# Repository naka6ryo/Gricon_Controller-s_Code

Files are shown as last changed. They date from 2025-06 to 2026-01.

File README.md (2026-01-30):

# Gricon_Controller-s_Code

2024/12/27に桃山大学テック部主催で開催されたハッカソンに出展した作品 **Gricon** のコントローラー側プログラムです（2024/12/28 時点）。

このArduinoプログラムは、IMU（姿勢センサ）、曲げセンサ、モーターを統合し、姿勢推定・屈曲検出・振動出力を通じて新しい入力体験を提供します。

公式サイト：https://gricon.netlify.app/

## 🎥 デモ動画

Gricon デモ動画 (https://youtu.be/qLPBSaw1i-E?si=rnXXbKDZcDVdmmQi)

---

## 🔗 関連リンク

- 🎮 **ゲーム側のプログラム（Unity）**  
  https://github.com/kdix-23-240/NewControllerProject-MomoyamaHack

- 📄 **作品に関する情報・ソースコードの解説・開発の流れの説明（Notion）**  
  https://flossy-band-678.notion.site/Gricon-Arduino-Unity-16a9ff2ca96c8032b9a5cc3768512383?pvs=4

---

## 📌 特徴 / Features

- **9軸IMUセンサ（LSM9DS1）** によるピッチ・ロール・ヨーの推定  
- **Madgwickフィルタ** による高精度な姿勢推定  
- **曲げセンサ** を使ったアナログ入力処理と平滑化  
- **加速度のグローバル変換・振動検出** によるリアクティブ入力対応  
- **振動モーター出力** を通じたハプティクスフィードバック  
- **シリアル通信** による外部機器（ゲーム）との双方向連携  

---

## 🔧 使用ハードウェア

- Arduino Nano 33 BLE Sense または LSM9DS1 搭載の互換ボード  
- 曲げセンサ（アナログ入力：A7）  
- 振動モーター（デジタル出力：D9）  
- 外部通信：Serial1（9600bps）

---

## 📷 回路図

以下は、本デバイスの回路図です（Arduino Nano 33 BLE + 曲げセンサ + モータ + Bluetooth構成）：

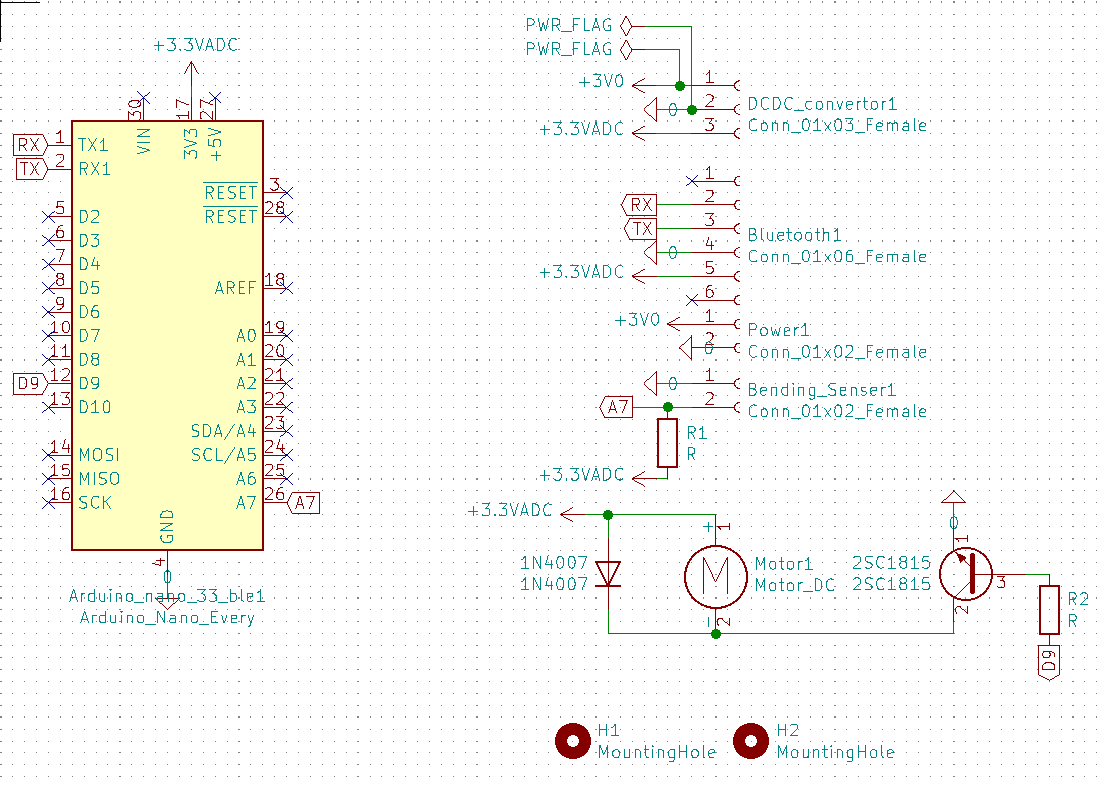
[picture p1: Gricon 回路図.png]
Gricon回路図


---

## 📤 センサ出力フォーマット

コントローラは以下のフォーマットで**バイナリ形式**のデータを送信します。

[S][pitch (2 bytes)][roll (2 bytes)][yaw (2 bytes)][bend (1 byte)]

- `S`: データ開始を示すヘッダ（1バイト）  
- `pitch`, `roll`, `yaw`: 姿勢角（各2バイト、0.1°単位）  
- `bend`: 曲げセンサ値（0〜20の範囲にクランプ）

---

## 🔁 モーター制御プロトコル（Serial1 受信）

シリアル経由で以下の1文字コマンドを送ることで、モーターの振動出力パターンを変更可能：

| コマンド | 周波数 (Hz相当) | デューティ比 | 内容 |
|---|---|---|---|
| `'1'` | 約25Hz | 40% | 弱い振動 |
| `'2'` | 約50Hz | 20% | 中程度の振動 |
| `'3'` | 約100Hz | 12.5% | 強い振動 |
| `'4'` | 約125Hz | 90% | 連続振動 |
| その他 | - | 0% | モーター停止 |

---

## 🧭 キャリブレーション

プログラム開始時に自動実行され、地磁気・ジャイロのオフセットや曲げセンサの初期値を取得・補正します。

---

## 🔄 処理周期とスムージング

- 処理周期：1msごとのループ実行（約100Hz）  
- 各種センサ値に対してフィルタ係数を用いた平滑化処理あり  
- 姿勢角の推定には Madgwick フィルタを使用

---

## 🚀 セットアップコード例

```cpp
void setup() {
  Serial.begin(9600);       // デバッグ用
  Serial1.begin(9600);      // 外部機器との通信
  pinMode(motorPin, OUTPUT);
  initializeIMU();
  delay(100);
}
```

## 📚 使用ライブラリ

| ライブラリ名 | 説明 | インストール方法 |
|---|---|---|
| Arduino_LSM9DS1 | IMU（加速度・ジャイロ・地磁気）センサ用 | Arduino IDE → ライブラリマネージャから検索して導入 |
| MadgwickAHRS | 姿勢推定アルゴリズム | Arduino IDE → ライブラリマネージャから検索して導入 |

---

## 📝 ライセンス

このプロジェクトは [MIT License](https://opensource.org/licenses/MIT) のもとで公開されています。

# Gricon Controller Code

This repository contains the **controller-side program** for **Gricon**, a project exhibited at a hackathon hosted by the **Momoyama University Tech Club** on **December 27, 2024** (status as of **December 28, 2024**).

This Arduino program integrates an **IMU (inertial measurement unit)**, a **flex sensor**, and a **vibration motor** to provide a new input experience through **orientation estimation**, **bend detection**, and **haptic feedback**.

Official site: https://gricon.netlify.app/

---

## 🎥 Demo Video

Gricon Demo Video (https://youtu.be/qLPBSaw1i-E?si=rnXXbKDZcDVdmmQi)

---

## 🔗 Related Links

- 🎮 **Game-side program (Unity)**  
  https://github.com/kdix-23-240/NewControllerProject-MomoyamaHack

- 📄 **Project details / source code explanation / development process (Notion)**  
  https://flossy-band-678.notion.site/Gricon-Arduino-Unity-16a9ff2ca96c8032b9a5cc3768512383?pvs=4

---

## 📌 Features

- **9-axis IMU (LSM9DS1)** for estimating **pitch / roll / yaw**
- **High-accuracy orientation estimation** using the **Madgwick filter**
- **Analog flex sensor processing** with smoothing
- **Global-frame acceleration conversion & vibration detection** for reactive input
- **Haptic feedback** via vibration motor output
- **Bidirectional communication** with external devices (e.g., a game) via **serial**

---

## 🔧 Hardware Used

- Arduino Nano 33 BLE Sense or a compatible board with LSM9DS1
- Flex sensor (analog input: A7)
- Vibration motor (digital output: D9)
- External communication: Serial1 (9600 bps)

---

## 📷 Circuit Diagram

Below is the circuit diagram for this device (Arduino Nano 33 BLE + flex sensor + motor + Bluetooth configuration):

Gricon Circuit Diagram

---

## 📤 Sensor Output Format

The controller sends data in the following **binary** format:

`[S][pitch (2 bytes)][roll (2 bytes)][yaw (2 bytes)][bend (1 byte)]`

- `S`: 1-byte header indicating the start of a packet  
- `pitch`, `roll`, `yaw`: Euler angles (2 bytes each, in 0.1° units)  
- `bend`: flex sensor value (clamped to 0–20)

---

## 🔁 Motor Control Protocol (Serial1 Receive)

You can change the vibration output pattern by sending a **single-character command** over serial:

| Command | Frequency (approx.) | Duty Cycle | Description |
|:---:|:---|:---:|---|
| `'1'`  | ~25 Hz | 40% | Weak vibration |
| `'2'`  | ~50 Hz | 20% | Medium vibration |
| `'3'`  | ~100 Hz | 12.5% | Strong vibration |
| `'4'`  | ~125 Hz | 90% | Continuous vibration |
| Other  | – | 0% | Motor off |

---

## 🧭 Calibration

Calibration runs automatically at startup to obtain and compensate:

- Magnetometer / gyroscope offsets  
- Initial baseline for the flex sensor  

---

## 🔄 Loop Rate & Smoothing

- Loop cycle: executed every 1 ms (≈ 100 Hz)  
- Sensor values are smoothed using filter coefficients  
- Orientation estimation uses the Madgwick filter

---

## 🚀 Setup Code Example

```cpp
void setup() {
  Serial.begin(9600);       // For debugging
  Serial1.begin(9600);      // Communication with external device
  pinMode(motorPin, OUTPUT);
  initializeIMU();
  delay(100);
}
```

📚 Libraries Used
Library	Description	Installation Method
Arduino_LSM9DS1	IMU (accel / gyro / magnetometer) library	Arduino IDE → Library Manager → search & install
MadgwickAHRS	AHRS orientation estimation algorithm	Arduino IDE → Library Manager → search & install
📝 License

This project is released under the MIT License:
https://opensource.org/licenses/MIT

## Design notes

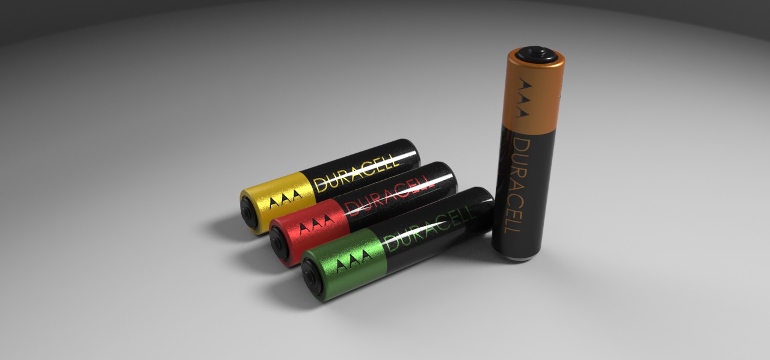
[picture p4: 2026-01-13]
Hardware/aaa-battery--2/Renderings/AAA_.jpg

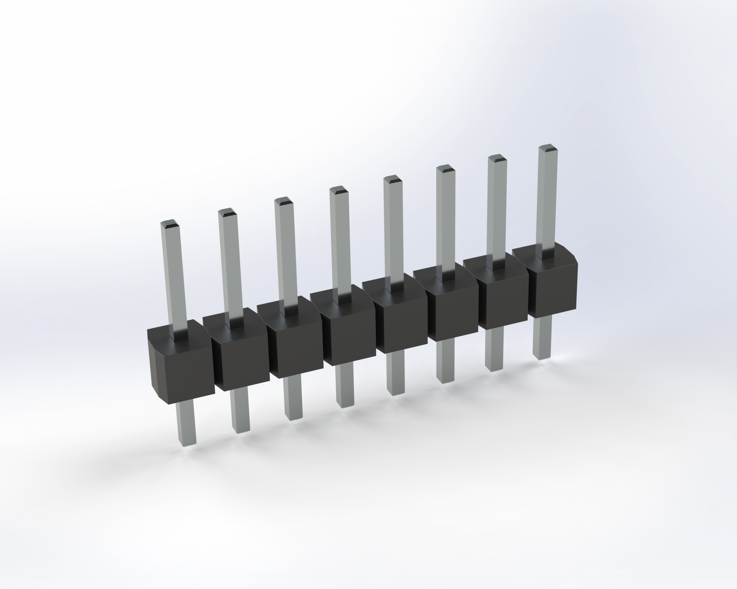
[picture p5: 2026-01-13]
Hardware/male-header-pins-1.snapshot.11/Male Header.png

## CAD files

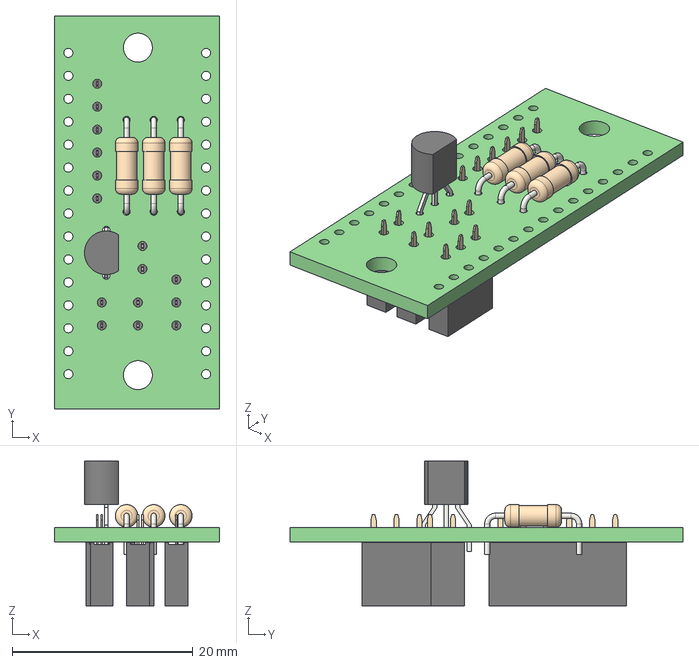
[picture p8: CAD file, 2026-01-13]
Cuicuit/Cuicuit.step
18.3 x 43.5 x 16.0 mm

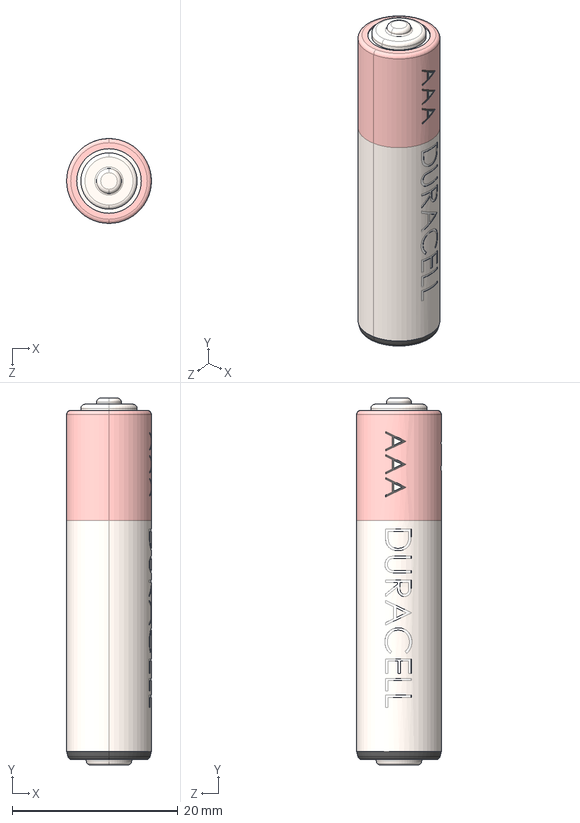
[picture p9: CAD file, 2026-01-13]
Hardware/aaa-battery--2/AAA Battery.STEP
10.2 x 44.4 x 10.2 mm

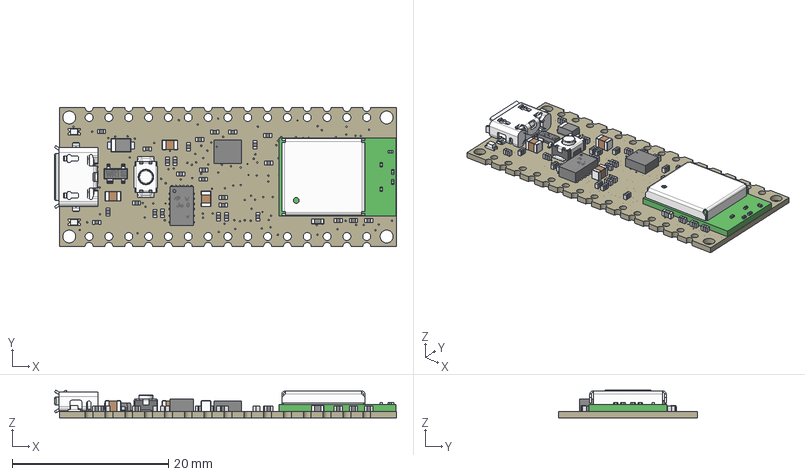
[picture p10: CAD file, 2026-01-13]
Hardware/arduino-nano-33-ble-1.snapshot.2/Nano33BLE/Nano33BLE.step
43.8 x 17.8 x 3.57 mm
Board (1)
LSM9DS1TR_LGA-24_3X3P5X1_STM v1
ZX62-AB-5PA (1)
IoT_HSMG-C190 LED v1 x 2
IoT_MPM3610 Step-Down Module v1
User Library-arduino_nano_reset core
User Library-arduino_nano_reset shell
RC0402FR-071KL RC0402N_YAG v1 x 27
BLM18EG101TN1D v1
C0805C472KDRACTU v1 x 3
PMEG6020AELRX v1
IoT_PRTR5V0U2X Protection Diode v1
NINA-B306-00B-00--3DModel-STEP-56544 v1

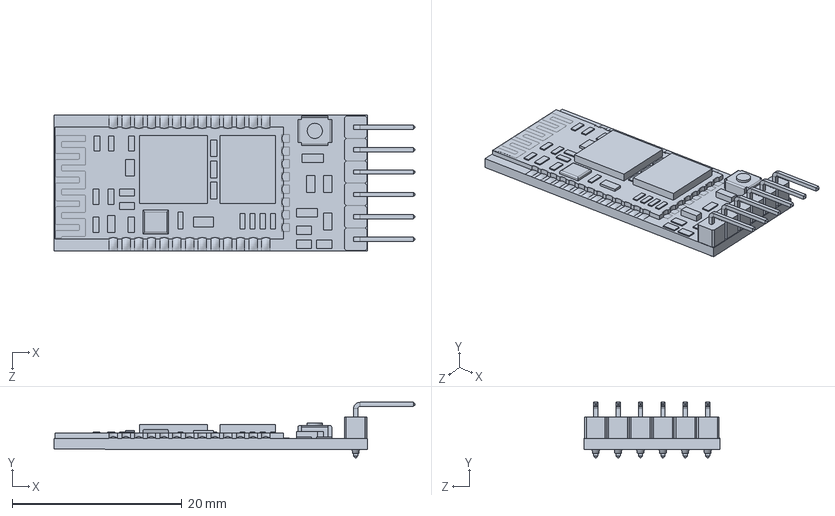
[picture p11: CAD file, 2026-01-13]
Hardware/bluetooth-module-hc-05-1.snapshot.4/Bluetooth Module HC-05/HC-05.SLDPRT
42.6 x 6.55 x 16.0 mm

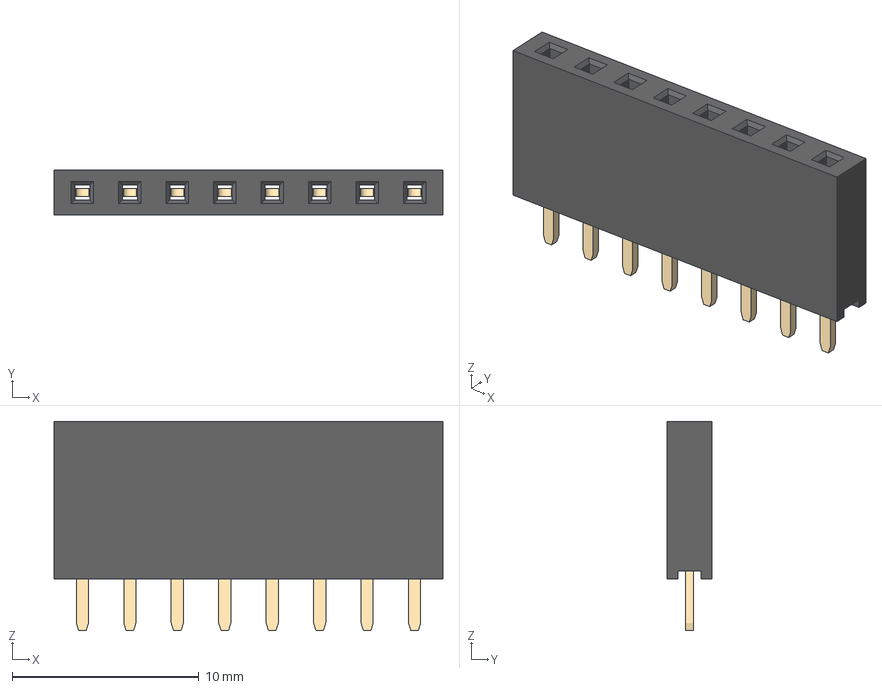
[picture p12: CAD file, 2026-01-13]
Hardware/cad-8-pin-header-1.snapshot.2/1_Dupont_Stiftleiste v6.3mf
20.8 x 2.39 x 11.2 mm

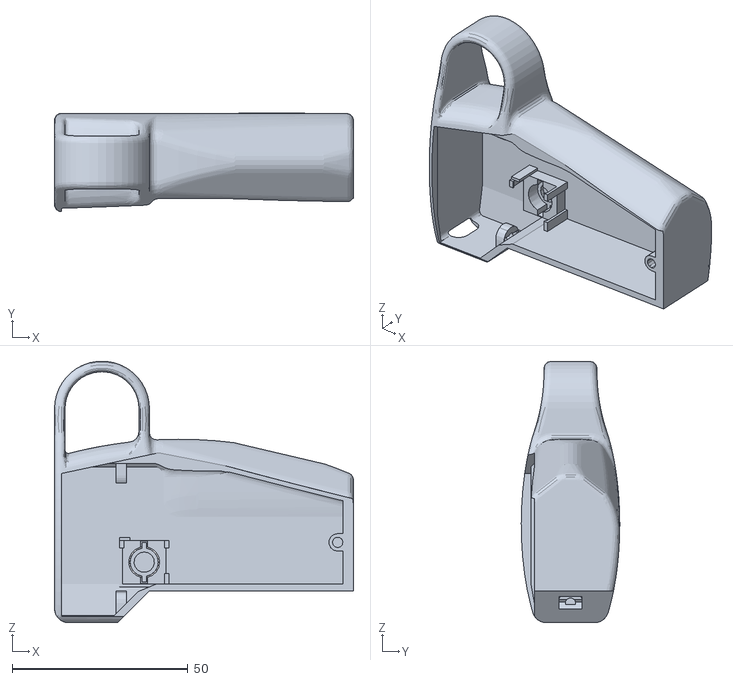
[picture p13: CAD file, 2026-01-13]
Hardware/for 3Dprints/Body_compleat01.stl
85.0 x 28.0 x 74.3

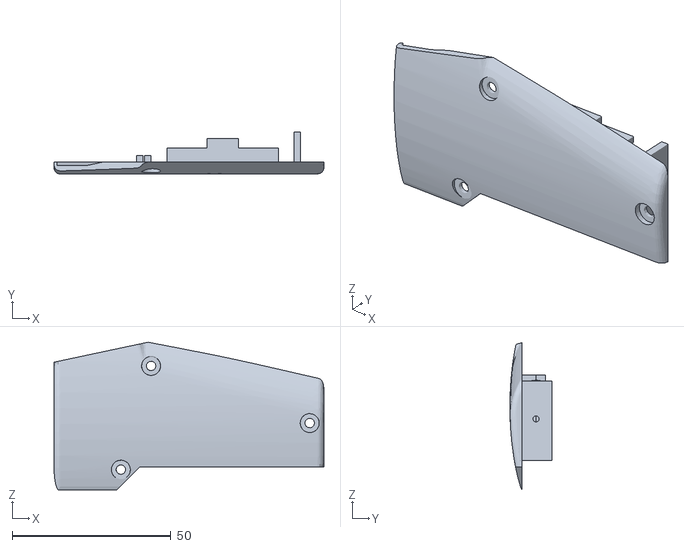
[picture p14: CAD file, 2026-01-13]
Hardware/for 3Dprints/done/Body_compleat02.stl
85.0 x 13.3 x 46.5

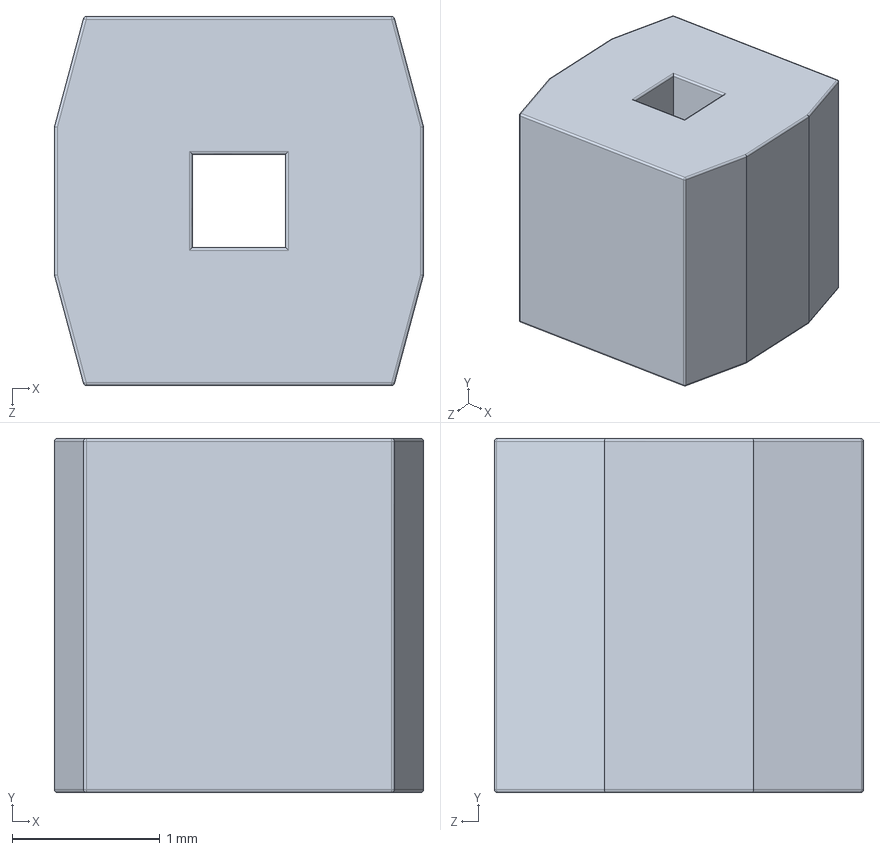
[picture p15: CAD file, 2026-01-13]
Hardware/male-header-pins-1.snapshot.11/Spacer.SLDPRT
2.50 x 2.40 x 2.50 mm

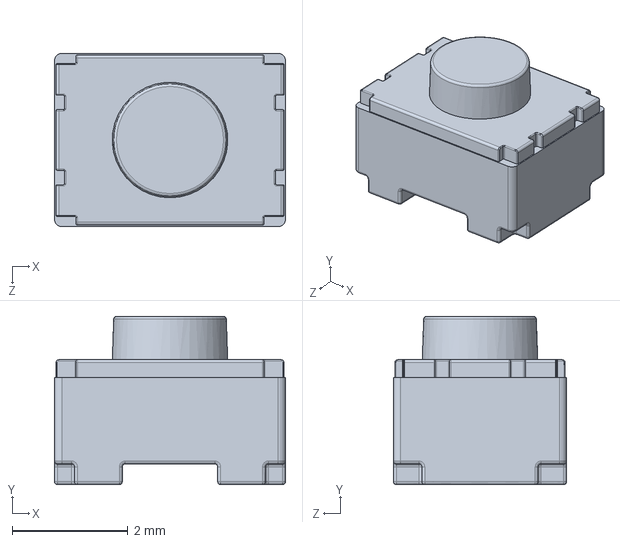
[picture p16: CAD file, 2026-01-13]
Hardware/bluetooth-module-hc-05-1.snapshot.4/Bluetooth Module HC-05/tactileswitch-short.SLDPRT
4.00 x 2.91 x 3.00 mm

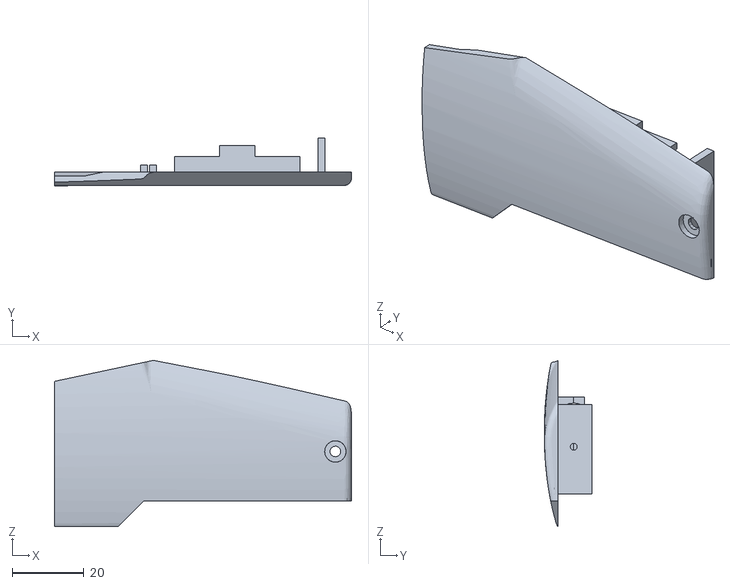
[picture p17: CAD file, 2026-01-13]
Hardware/for 3Dprints/Body_compleat02.stl
83.0 x 13.3 x 46.5

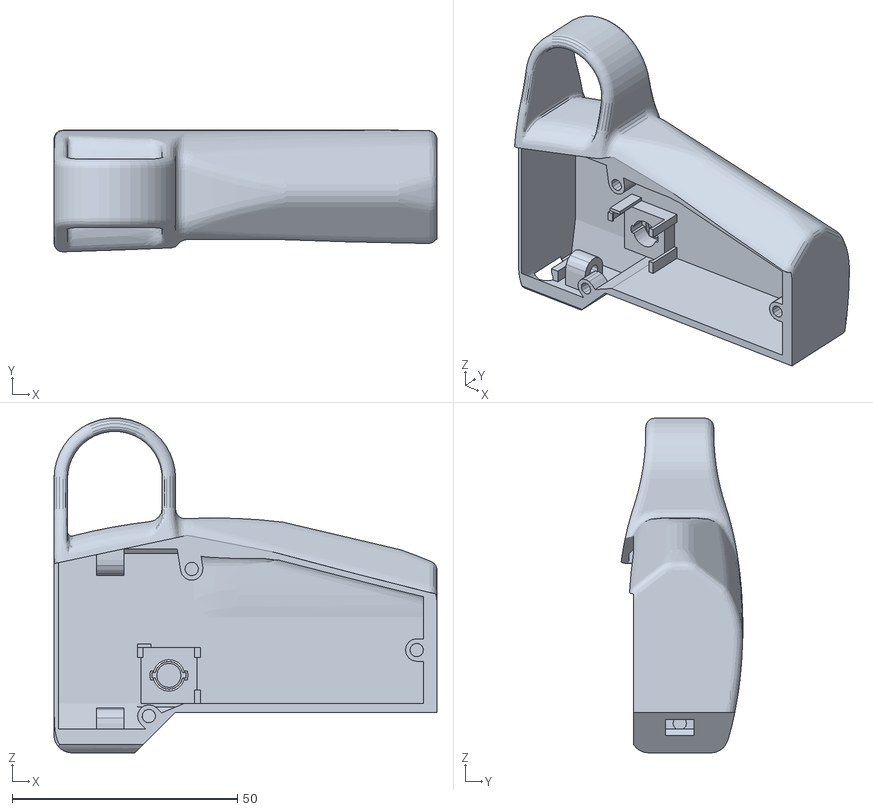
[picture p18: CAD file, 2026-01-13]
Hardware/for 3Dprints/done/Body_compleated01.stl
85.0 x 27.0 x 74.3

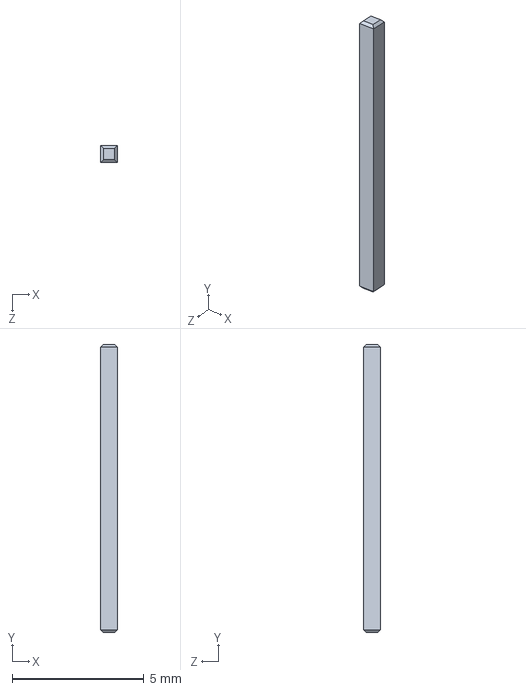
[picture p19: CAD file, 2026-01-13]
Hardware/male-header-pins-1.snapshot.11/Male Header Pin.SLDPRT
0.63 x 10.9 x 0.63 mm

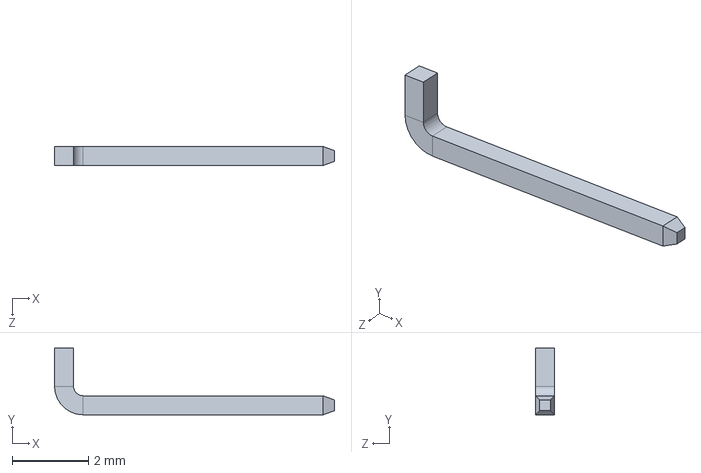
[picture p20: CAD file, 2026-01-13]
Hardware/bluetooth-module-hc-05-1.snapshot.4/Bluetooth Module HC-05/HC-05 part6.SLDPRT
7.35 x 1.75 x 0.5 mm

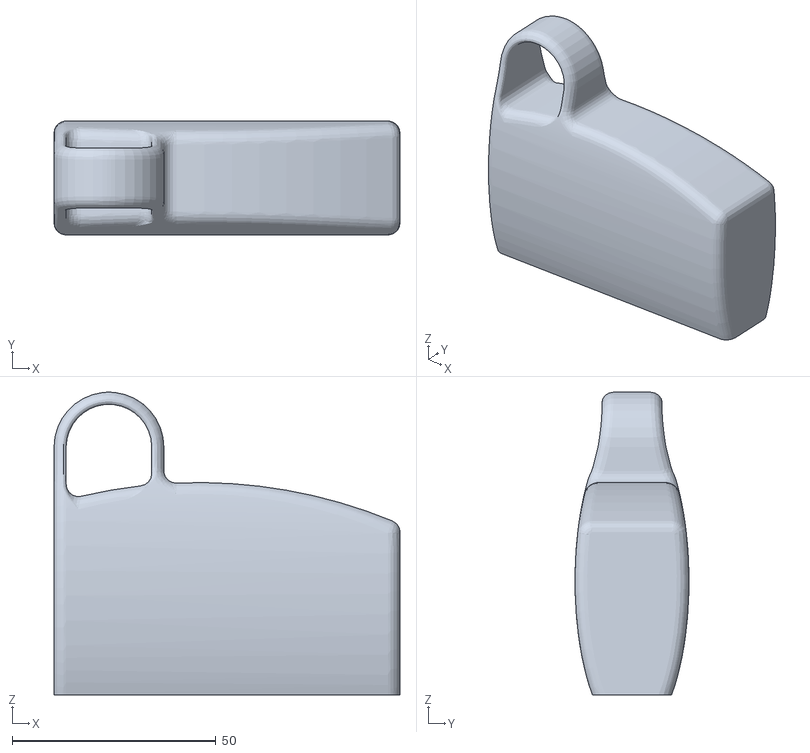
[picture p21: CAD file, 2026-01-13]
Hardware/for 3Dprints/done/Body03.stl
85.0 x 28.0 x 74.3

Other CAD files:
Hardware/male-header-pins-1.snapshot.11/Male Header Pin Config.STEP
Hardware/bluetooth-module-hc-05-1.snapshot.4/Bluetooth Module HC-05/HC-05 part8.SLDPRT
Hardware/for 3Dprints/done/Body04.stl
Cuicuit/Cuicuit/Cuicuit.ipt
Hardware/Assembly.iam
Hardware/Body01.ipt
Hardware/Body02.ipt
Hardware/Body03.ipt
Hardware/Body04.ipt
Hardware/Body_compleat01.ipt
Hardware/Body_compleat01_old.ipt
Hardware/Body_compleat02.ipt
Hardware/Body_compleat02_old.ipt
Hardware/OldVersions/Assembly.0056.iam
Hardware/OldVersions/Body01.0002.ipt
Hardware/OldVersions/Body02.0005.ipt
Hardware/OldVersions/Body03.0006.ipt
Hardware/OldVersions/Body04.0012.ipt
Hardware/OldVersions/Body_compleat01.0065.ipt
Hardware/OldVersions/Body_compleat02.0056.ipt
Hardware/OldVersions/Part2.0003.ipt
Hardware/OldVersions/Part3.0001.ipt
Hardware/OldVersions/bend_sensor.0001.ipt
Hardware/OldVersions/cable - コピー.0002.ipt
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

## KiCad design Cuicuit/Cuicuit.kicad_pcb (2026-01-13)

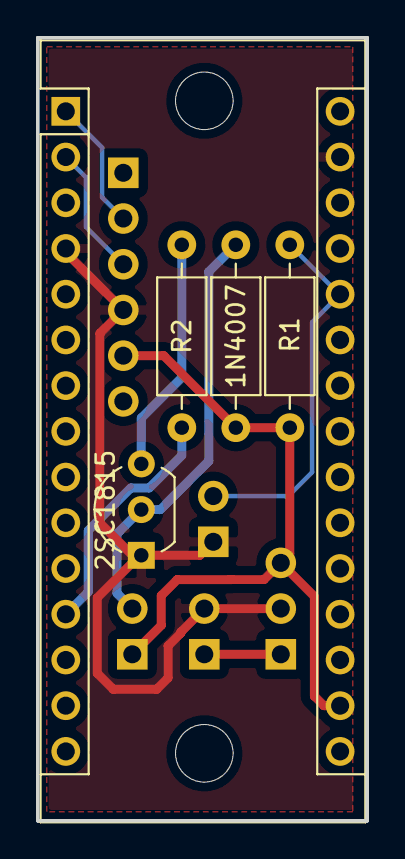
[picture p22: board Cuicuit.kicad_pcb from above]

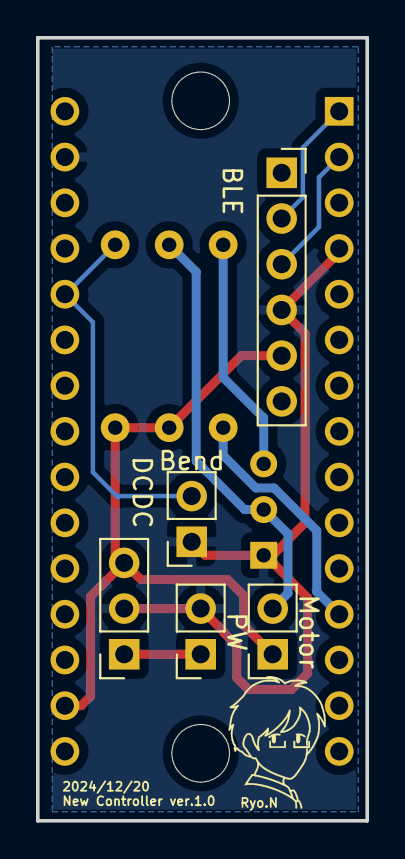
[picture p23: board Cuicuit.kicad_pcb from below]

Board: 2 copper layers, 18.3 x 43.5 mm, 12 parts (5 on the bottom side), 9 nets.

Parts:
1N4007: 1N4007; R_Axial_DIN0207_L6.3mm_D2.5mm_P10.16mm_Horizontal
2SC1815: 2SC1815; TO-92_Inline_Wide
Arduino_nano_33_ble1: Arduino_Nano_Every; Arduino_Nano
BLE: Conn_01x06_Female; PinSocket_1x06_P2.54mm_Vertical
Bend: Conn_01x02_Female; PinSocket_1x02_P2.54mm_Vertical
DCDC: Conn_01x03_Female; PinSocket_1x03_P2.54mm_Vertical
H1, H2: MountingHole; MountingHole_3.2mm_M3
Motor: Motor_DC; PinSocket_1x02_P2.54mm_Vertical
PW: Conn_01x02_Female; PinSocket_1x02_P2.54mm_Vertical
R1, R2: R; R_Axial_DIN0207_L6.3mm_D2.5mm_P10.16mm_Horizontal

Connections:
0: 2SC1815.1, Arduino_nano_33_ble1.4, Arduino_nano_33_ble1.29, BLE.4, Bend.1, DCDC.2, PW.2
+3.3VADC: 1N4007.2, Arduino_nano_33_ble1.17, BLE.5, DCDC.3, Motor.1, R1.2
+3V0: DCDC.1, PW.1
A7: Arduino_nano_33_ble1.26, Bend.2, R1.1
D9: Arduino_nano_33_ble1.12, R2.2
unnamed: 1N4007.1, 2SC1815.2, Motor.2
unnamed: 2SC1815.3, R2.1
RX: Arduino_nano_33_ble1.1, BLE.2
TX: Arduino_nano_33_ble1.2, BLE.3

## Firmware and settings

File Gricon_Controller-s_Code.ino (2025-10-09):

// ===============================
// 必要なライブラリの読み込み
// ===============================
#include <Arduino_LSM9DS1.h> // LSM9DS1 IMU用ライブラリ
// MadgwickAHRS.h を排除し、自前クォータニオン姿勢推定(Mahony風)を実装

// ===============================
// ピン定義
// ===============================
#define ANALOG_PIN 7 // 曲げセンサ接続アナログピン
#define motorPin 9   // モーター出力ピン

// 自前姿勢推定用クォータニオン (q0 + q1*i + q2*j + q3*k)
volatile float q0 = 1.0f, q1 = 0.0f, q2 = 0.0f, q3 = 0.0f;

// Mahony風フィードバックゲイン
float Kp = 2.0f;                                                  // 比例ゲイン（大きいほど加速度/地磁気へ早く収束）
float Ki = 0.0f;                                                  // 積分ゲイン（必要ならドリフト抑制用に有効化）
float integralFBx = 0.0f, integralFBy = 0.0f, integralFBz = 0.0f; // 積分項

unsigned long lastMicros = 0; // Δt計算用

// ===============================
// 状態変数・初期化用
// ===============================
int in = 5, in0 = 5;                      // シリアル入力値（前回値と現在値）
int l = 0;                                // メインループカウンタ
float bend0 = 0, bend_past = 0, bend = 0; // 曲げセンサ値（初期基準・過去・現在）

// ===============================
// フィルタリング・補正係数
// ===============================
float a = 0.1;          // 地磁気補正係数
float p = 0.5, r = 0.5; // ピッチ・ロール平滑化係数
float yaw_y = 0.3;      // ヨー角平滑化係数
float b = 0.1;          // 曲げセンサ平滑化係数
float T = 0.01;         // サンプリング周期（秒）（実際は毎ループで更新）
float c = 0.1, d = 0.1; // 加速度・速度のフィルタ係数

// ===============================
// 地磁気フェード設定（ピッチ角依存）
// ピッチ角の絶対値 |pitch| が start 以下では地磁気100%、end 以上では0%。
// その間は線形にフェードアウトします。
// 値は度数法[deg]。
// 例: 45degから減衰を開始し、75degで完全に無効化。
const float MAG_FADE_START_DEG = 90.0f;
const float MAG_FADE_END_DEG = 90.0f;

// ===============================
// センサ補正用のオフセット・スケール
// ===============================
// 地磁気オフセットベクトル（mag_offset）
float mag_offset[3] = {-3.7991, 46.8373, -13.9604};

// 楕円体補正行列（mag_correction）※3x3対称行列
float mag_correction[3][3] = {
    {0.0538, 0.0020, 0.0027},
    {0.0020, 0.0401, -0.0003},
    {0.0027, -0.0003, 0.0456}};

float acc_offset[3] = {-0.02, 0.01, 0.0}; // 加速度オフセット
float gyro_offset[3] = {0.0, 0.0, 0.0};   // ジャイロオフセット（初期補正で決定）

// ===============================
// IMUデータ格納用の配列
// ===============================
float acc[3] = {0}, gyro[3] = {0}, mag[3] = {0}; // センサ値
float acc_prev[3] = {0}, acc_global[3] = {0, 0, 1}, acc_global_prev[3] = {0, 0, 1};
float vel[3] = {0}, vel_prev[3] = {0}; // 速度（各軸）
float pos[3] = {0};                    // 位置（各軸）

// ===============================
// 姿勢角・ヨー角補正用
// ===============================
float pitch = 0, roll = 0, yaw = 0;
float pitch0 = 0, roll0 = 0, yaw_g0 = 0;
float yaw_sim = 0, yaw_s = 0, yaw_sm = 0;
float yaw_m = 0;         // 出力用ヨー角（初期オフセット基準）
float gyro_sim[3] = {0}; // 初期ジャイロ値積算用

// ===============================
// 振動検出用フラグ
// ===============================
int baibx, baiby, baibz;

// ===============================
// IMUの初期化関数
// ===============================
void initializeIMU()
{
  if (!IMU.begin())
  {
    while (1)
      ; // 初期化失敗時に停止
  }
  lastMicros = micros();
}

// ===============================
// 初期キャリブレーション関数
// ===============================
void calibrateSensors()
{
  digitalWrite(LEDG, HIGH);
  for (int i = 0; i < 300; i++)
  {
    digitalWrite(LEDR, i % 10 < 5 ? LOW : HIGH);
    readIMUSensors(true);
    delay(10);
  }

  // クォータニオン初期安定化（約15秒）
  for (int i = 0; i < 1500; i++)
  {
    digitalWrite(LEDR, i % 100 < 50 ? LOW : HIGH);
    readIMUSensors(true);
    // 仮のΔt（10ms固定）で姿勢更新
    // NOTE: キャリブレーション中は時間精度より安定化優先のため固定値
    float dt = 0.01f;
    // 姿勢更新
    // （地磁気を含む更新関数は後方で定義）
    // updateQuaternion 定義後にコンパイラが解決できるようプロトタイプを前方宣言してもよいが
    // ここでは後方に実装されるため関数プロトタイプ宣言を追加する。
    // → ファイル先頭付近にプロトタイプを追加済みではないので後方に定義を移動し再度読み直し。
    // 暫定: ここでは一旦後で置換されるダミー呼び出し(後で本体実装)。
    // 実装後: updateQuaternion(dt);
    // ---- 呼び出し ----
    // 本体はファイル後半に追加
    extern void updateQuaternion(float dt);
    updateQuaternion(dt);
    for (int j = 0; j < 3; j++)
      gyro_sim[j] += gyro[j];
    delay(10);
  }

  for (int i = 0; i < 3; i++)
    gyro_offset[i] = gyro_sim[i] / 500.0;

  // 現在のクォータニオンから初期ヨー角オフセット算出
  float yaw_raw = atan2f(2.0f * (q0 * q3 + q1 * q2), 1.0f - 2.0f * (q2 * q2 + q3 * q3)) * 180.0f / PI;
  yaw_sm = yaw_raw; // 初期オフセット
  yaw_m = 0.0f;
  bend0 = analogRead(ANALOG_PIN);

  for (int i = 0; i < 10; i++)
  {
    digitalWrite(LEDG, HIGH);
    digitalWrite(motorPin, HIGH);
    delay(50);
    digitalWrite(LEDG, LOW);
    digitalWrite(motorPin, LOW);
    delay(50);
  }
}

// ===============================
// IMU読み取り・補正
// ===============================
void readIMUSensors(bool applyOffset)
{
  IMU.readAcceleration(acc[0], acc[1], acc[2]);
  IMU.readGyroscope(gyro[0], gyro[1], gyro[2]);
  IMU.readMagneticField(mag[0], mag[1], mag[2]);

  // 一時変数に地磁気読み取り値を保存
  float mag_raw[3];
  for (int i = 0; i < 3; i++)
  {
    mag_raw[i] = mag[i] - mag_offset[i];
  }

  // 楕円体補正（A行列適用：mag = A × (raw - offset)）
  for (int i = 0; i < 3; i++)
  {
    mag[i] = 0;
    for (int j = 0; j < 3; j++)
    {
      mag[i] += mag_correction[i][j] * mag_raw[j];
    }
  }

  // ★ 地磁気ベクトルの正規化を追加（安全チェック付き）★
  float mag_norm = sqrt(mag[0] * mag[0] + mag[1] * mag[1] + mag[2] * mag[2]);
  if (mag_norm > 0.01)
  {
    for (int i = 0; i < 3; i++)
      mag[i] /= mag_norm;
  }

  // ジャイロ・加速度のオフセット補正
  if (applyOffset)
  {
    for (int i = 0; i < 3; i++)
      gyro[i] += gyro_offset[i];
  }
  else
  {
    gyro[0] = -gyro[0] + gyro_offset[0];
    gyro[1] = -gyro[1] + gyro_offset[1];
    gyro[2] = gyro[2] + gyro_offset[2] - 0.0015;
    for (int i = 0; i < 3; i++)
      acc[i] += acc_offset[i];
  }

  // フィルタ更新はループ側で updateQuaternion() を呼ぶ
}

// ===============================
// 姿勢角（ピッチ・ロール・ヨー）更新
// ===============================
void updateOrientation()
{
  // クォータニオン -> オイラー角 (Tait-Bryan ZYX: yaw(z), pitch(y), roll(x))
  float roll_raw = atan2f(2.0f * (q0 * q1 + q2 * q3), 1.0f - 2.0f * (q1 * q1 + q2 * q2)) * 180.0f / PI;
  float pitch_raw = asinf(2.0f * (q0 * q2 - q3 * q1)) * 180.0f / PI;
  float yaw_raw = atan2f(2.0f * (q0 * q3 + q1 * q2), 1.0f - 2.0f * (q2 * q2 + q3 * q3)) * 180.0f / PI;

  // 初期オフセット補正
  float yaw_now = yaw_raw - yaw_sm;
  if (yaw_now > 180.0f)
    yaw_now -= 360.0f;
  if (yaw_now < -180.0f)
    yaw_now += 360.0f;

  // 平滑化
  pitch = pitch_raw * p + (1 - p) * pitch;
  roll = roll_raw * r + (1 - r) * roll;
  yaw_m = yaw_now * yaw_y + (1 - yaw_y) * yaw_g0; // yaw_g0 は前回 yaw_m を保持
}

// ===============================
// 加速度 → グローバル座標変換
// ===============================
// クォータニオンによるベクトル回転 ( acc_body -> acc_global )
void rotateAccelToGlobal(float ax, float ay, float az, float &gx, float &gy, float &gz)
{
  // q * v * q_conj （vは純虚部クォータニオン(0,ax,ay,az)）
  float qx = q1, qy = q2, qz = q3, qw = q0;
  // 1) q * v
  float vw = -(qx * ax + qy * ay + qz * az);
  float vx = qw * ax + (qy * az - qz * ay);
  float vy = qw * ay + (qz * ax - qx * az);
  float vz = qw * az + (qx * ay - qy * ax);
  // 2) (q * v) * q_conj
  gx = -vw * qx + vx * qw - vy * qz + vz * qy;
  gy = -vw * qy + vy * qw - vz * qx + vx * qz;
  gz = -vw * qz + vz * qw - vx * qy + vy * qx;
}

// ===============================
// 加速度の更新と振動検出
// ===============================
void updateAcceleration()
{
  for (int i = 0; i < 3; i++)
    acc[i] = c * acc[i] + (1 - c) * acc_prev[i];

  // クォータニオンで回転（重力は未除去。必要なら gz -= 1.0f などで補正）
  rotateAccelToGlobal(acc[0], acc[1], acc[2], acc_global[0], acc_global[1], acc_global[2]);

  for (int i = 0; i < 3; i++)
    acc_global[i] = c * acc_global[i] + (1 - c) * acc_global_prev[i];

  baibx = fabsf(acc_global[0]) > 0.5;
  baiby = fabsf(acc_global[1]) > 0.5;
  baibz = fabsf(acc_global[2] - acc_global_prev[2]) > 0.04 ? 0 : 0;
}

// ===============================
// 速度更新（簡易積分）
// ===============================
void updateVelocity()
{
  for (int i = 0; i < 3; i++)
  {
    vel[i] = (1 - d) * vel_prev[i] + d * (acc_global[i] + acc_global_prev[i]) * T / 2.0;
  }
}

// ===============================
// 位置更新（簡易積分）
// ===============================
void updatePosition()
{
  for (int i = 0; i < 3; i++)
  {
    pos[i] += (vel[i] + vel_prev[i]) * T / 2.0;
  }
}

// ===============================
// モータ制御処理（シリアル入力に基づく）
// ===============================
void updateMotorState()
{
  in0 = in;
  if (Serial1.available() > 0)
  {
    in = Serial1.read();

    // '6'受信時: 現在のヨー角を基準0に再設定（yaw_sm を更新）。
    // モードは変えないため、in は直前の値に戻す。
    if (in == '6')
    {
      float yaw_raw_now = atan2f(2.0f * (q0 * q3 + q1 * q2), 1.0f - 2.0f * (q2 * q2 + q3 * q3)) * 180.0f / PI;
      yaw_sm = yaw_raw_now; // 以後 yaw_now = yaw_raw - yaw_sm = 0 で基準化
      in = in0;             // モーターモードは維持
    }

    if (in < '1' || in > '5')
      in = in0;
  }
  else
  {
    in = in0;
  }

  int flashRate = 0;
  float flashRate_deno = 0;
  if (in == '1')
  {
    flashRate = 20;
    flashRate_deno = 0.4;
  }
  else if (in == '2')
  {
    flashRate = 40;
    flashRate_deno = 0.2;
  }
  else if (in == '3')
  {
    flashRate = 80;
    flashRate_deno = 0.125;
  }
  else if (in == '4')
  {
    flashRate = 100;
    flashRate_deno = 0.9;
  }
  else
  {
    digitalWrite(motorPin, LOW);
    digitalWrite(LEDR, HIGH);
    digitalWrite(LEDG, LOW);
    return;
  }

  digitalWrite(LEDG, HIGH);
  bool motorOn = (l % flashRate < flashRate * flashRate_deno);
  digitalWrite(motorPin, motorOn ? HIGH : LOW);
  digitalWrite(LEDR, motorOn ? LOW : HIGH);
}

// ===============================
// データ送信（シリアル通信）
// ===============================
void outputDataAsBytes()
{
  int16_t angle_pitch = (int16_t)(pitch * 10.0);
  int16_t angle_roll = (int16_t)(roll * 10.0);
  int16_t angle_yaw = (int16_t)(yaw_m * 10.0);
  int16_t bend_to_send = (int16_t)(bend * 10.0);

  uint8_t buffer[sizeof(int16_t) * 4];
  memcpy(buffer, &angle_pitch, sizeof(int16_t));
  memcpy(buffer + sizeof(int16_t), &angle_roll, sizeof(int16_t));
  memcpy(buffer + 2 * sizeof(int16_t), &angle_yaw, sizeof(int16_t));
  memcpy(buffer + 3 * sizeof(int16_t), &bend_to_send, sizeof(int16_t));

  Serial1.write('S'); // ヘッダ送信
  Serial1.write(buffer, sizeof(buffer));
}

// ===============================
// 初期化処理
// ===============================
void setup()
{
  Serial.begin(9600);
  Serial1.begin(115200);
  pinMode(motorPin, OUTPUT);
  initializeIMU();
  delay(100);
}

// ===============================
// メインループ処理
// ===============================
void loop()
{
  // 最初のループのみ初期キャリブレーションを実行
  if (l == 0)
    calibrateSensors();

  // 曲げセンサの値を読み取り、初期値を引いて平滑化
  bend_past = bend;
  bend = analogRead(ANALOG_PIN) - bend0;
  bend = b * bend + (1 - b) * bend_past;

  // 直前の加速度・グローバル加速度・速度を保存（次の更新で使用）
  for (int i = 0; i < 3; i++)
  {
    acc_prev[i] = acc[i];
    acc_global_prev[i] = acc_global[i];
    vel_prev[i] = vel[i];
  }

  // 直前の姿勢角を保存（平滑化に使用）
  pitch0 = pitch;
  roll0 = roll;
  yaw_g0 = yaw_m;

  // IMU（加速度・ジャイロ・地磁気）のデータを読み取って補正
  readIMUSensors(false);

  // Δt計算
  unsigned long nowMicros = micros();
  float dt = (nowMicros - lastMicros) * 1e-6f;
  lastMicros = nowMicros;
  if (dt <= 0.0f || dt > 0.1f)
    dt = T; // 異常値ガード
  T = dt;   // 他処理用に更新

  // 姿勢クォータニオン更新
  updateQuaternion(dt);

  // シリアル入力値に応じてモータをON/OFF制御
  updateMotorState();

  // クォータニオンから姿勢角へ
  updateOrientation();

  // 加速度値をグローバル座標系に変換し、ノイズ除去・振動判定
  updateAcceleration();

  // 加速度をもとに速度を更新（簡易積分）
  updateVelocity();

  // 速度をもとに位置を更新（簡易積分）
  updatePosition();

  // ピッチ・ロール・ヨー角、曲げ量をシリアル通信で送信
  outputDataAsBytes();

  // ループカウンタ更新（4000を超えたら1に戻す）
  l++;
  if (l > 4000)
    l = 1;

  // 1ms待機（ループ周期制御）
  delay(1);
}

// ===============================
// クォータニオン更新関数 (Mahony風アルゴリズム)
// 入力: グローバル変数 gyro(rad/s), acc(g), mag(正規化済) / dt(s)
// ===============================
void updateQuaternion(float dt)
{
  // 調整ガイド:
  // 1) Kp: 大きくすると静止時の収束早いが動的環境で振動増える。1.0～5.0で調整。
  // 2) Ki: ジャイロバイアスが残る場合のみ 0.001〜0.05 程度で徐々に上げる。
  // 3) 地磁気がノイジーな環境（磁気干渉）では halfex/halfey/halfez の磁気項を無効化する実装分岐を追加推奨。
  // 4) 重力除去: グローバル加速度で動きのみ使いたい場合は updateAcceleration 内で acc_global[2] -= 1.0f などを検討。
  // 5) ドリフト評価: 十数秒静止させ yaw/pitch/roll の変化量をログし Kp/Ki を決める。
  // 6) 最適化: sqrtf 頻出箇所を近似 1/sqrt に変えてもOK (ARM CMSIS の arm_sqrt_f32 等)。
  float gx = gyro[0] * DEG_TO_RAD; // もともとdeg/sならRAD変換 (LSM9DS1はdps)
  float gy = gyro[1] * DEG_TO_RAD;
  float gz = gyro[2] * DEG_TO_RAD;

  // 加速度正規化
  float norm = sqrtf(acc[0] * acc[0] + acc[1] * acc[1] + acc[2] * acc[2]);
  if (norm > 0.0f)
  {
    float inv = 1.0f / norm;
    float ax = acc[0] * inv;
    float ay = acc[1] * inv;
    float az = acc[2] * inv;

    // 地磁気正規化（既に正規化済みだが二重防御）
    float mn = sqrtf(mag[0] * mag[0] + mag[1] * mag[1] + mag[2] * mag[2]);
    float mxn = mag[0], myn = mag[1], mzn = mag[2];
    if (mn > 0.01f)
    {
      float invm = 1.0f / mn;
      mxn *= invm;
      myn *= invm;
      mzn *= invm;
    }

    // 参照重力（クォータニオンから期待される重力方向）
    float halfvx = q1 * q3 - q0 * q2;        // 0.5 * vx 実装簡略化 (Mahony実装流用形)
    float halfvy = q0 * q1 + q2 * q3;        // 0.5 * vy
    float halfvz = q0 * q0 - 0.5f + q3 * q3; // 0.5 * vz

    // 地磁気参照（Mahony拡張）
    float hx = 2.0f * (mxn * (0.5f - q2 * q2 - q3 * q3) + myn * (q1 * q2 - q0 * q3) + mzn * (q1 * q3 + q0 * q2));
    float hy = 2.0f * (mxn * (q1 * q2 + q0 * q3) + myn * (0.5f - q1 * q1 - q3 * q3) + mzn * (q2 * q3 - q0 * q1));
    float bx = sqrtf(hx * hx + hy * hy);
    float bz = 2.0f * (mxn * (q1 * q3 - q0 * q2) + myn * (q2 * q3 + q0 * q1) + mzn * (0.5f - q1 * q1 - q2 * q2));

    float halfwx = bx * (0.5f - q2 * q2 - q3 * q3) + bz * (q1 * q3 - q0 * q2); // 0.5 * wx
    float halfwy = bx * (q1 * q2 - q0 * q3) + bz * (q0 * q1 + q2 * q3);        // 0.5 * wy
    float halfwz = bx * (q0 * q2 + q1 * q3) + bz * (0.5f - q1 * q1 - q2 * q2); // 0.5 * wz

    // 誤差 = (観測ベクトル×参照ベクトル) の形を Mahony 公式ベースで簡略
    // 地磁気項はピッチ角が大きいほど無効化（ウェイトを0へ）
    // 現在のクォータニオンからピッチ角を直接算出（度）
    float sp = 2.0f * (q0 * q2 - q3 * q1);
    if (sp > 1.0f)
      sp = 1.0f;
    else if (sp < -1.0f)
      sp = -1.0f;
    float pitch_deg_now = asinf(sp) * 180.0f / PI;
    float pitch_abs = fabsf(pitch_deg_now);
    float mag_w = 1.0f;
    if (MAG_FADE_END_DEG <= MAG_FADE_START_DEG)
    {
      // フェード区間が無効な場合は閾値でステップ切り替え
      mag_w = (pitch_abs <= MAG_FADE_START_DEG) ? 1.0f : 0.0f;
    }
    else if (pitch_abs <= MAG_FADE_START_DEG)
    {
      mag_w = 1.0f;
    }
    else if (pitch_abs >= MAG_FADE_END_DEG)
    {
      mag_w = 0.0f;
    }
    else
    {
      float t = (pitch_abs - MAG_FADE_START_DEG) / (MAG_FADE_END_DEG - MAG_FADE_START_DEG);
      mag_w = 1.0f - t; // 線形フェード
    }

    float halfex = (ay * halfvz - az * halfvy) + mag_w * (myn * halfwz - mzn * halfwy);
    float halfey = (az * halfvx - ax * halfvz) + mag_w * (mzn * halfwx - mxn * halfwz);
    float halfez = (ax * halfvy - ay * halfvx) + mag_w * (mxn * halfwy - myn * halfwx);

    // 積分項
    if (Ki > 0.0f)
    {
      integralFBx += Ki * halfex * dt;
      integralFBy += Ki * halfey * dt;
      integralFBz += Ki * halfez * dt;
    }
    else
    {
      integralFBx = integralFBy = integralFBz = 0.0f;
    }

    // 補正付きジャイロ
    gx += Kp * halfex + integralFBx;
    gy += Kp * halfey + integralFBy;
    gz += Kp * halfez + integralFBz;
  }

  // クォータニオン微分 q_dot = 0.5 * q ⊗ ω
  float qDot0 = 0.5f * (-q1 * gx - q2 * gy - q3 * gz);
  float qDot1 = 0.5f * (q0 * gx + q2 * gz - q3 * gy);
  float qDot2 = 0.5f * (q0 * gy - q1 * gz + q3 * gx);
  float qDot3 = 0.5f * (q0 * gz + q1 * gy - q2 * gx);

  // 積分
  q0 += qDot0 * dt;
  q1 += qDot1 * dt;
  q2 += qDot2 * dt;
  q3 += qDot3 * dt;

  // 正規化
  float nq = sqrtf(q0 * q0 + q1 * q1 + q2 * q2 + q3 * q3);
  if (nq > 0.0f)
  {
    float inv = 1.0f / nq;
    q0 *= inv;
    q1 *= inv;
    q2 *= inv;
    q3 *= inv;
  }
}

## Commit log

2025-06-07 AIによるコード改善（デバックなし）
2025-06-07 バイナリ通信への変更とコードの関数を用いた整理
2025-06-07 バイナリ通信の最適化（小数第1位まで）
2025-06-07 警告の振動数の調整
2025-06-07 握り具合の調整
2025-06-08 曲げセンサの閾値をゲーム側で制御
2025-06-08 曲げセンサの値の平滑化
2025-06-08 曲げセンサの範囲制限とそれによる通信の改良
2025-06-09 VScodeからの書き込み対応＆ヨー方向の制御系統の変更
2025-06-09 VScodeでの書き込み対応
2025-06-14 VScode上での書き込み用アップデート
2025-06-14 地磁気補正の改良
2025-06-14 地磁気キャリブレーションの更新及び初期値の配列化
2025-06-15 ピッチに応じたゲイン調整の導入
2025-06-15 曲げセンサの小数化
2025-06-15 ゲインのピッチ変化の削除
2025-06-15 待機時間の延長
2025-06-30 ヨー角の他角度の連動の修正
2025-10-09 近大プロトコン用更新
2026-01-13 Add Hard and Circuit
    [1_Dupont_Stiftleiste v6.3mf, 1_Dupont_Stiftleiste v6.ipt, AAA Battery.SLDPRT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]
